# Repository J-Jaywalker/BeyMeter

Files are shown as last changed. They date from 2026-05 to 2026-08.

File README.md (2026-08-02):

# BeyBeetle (WIP)

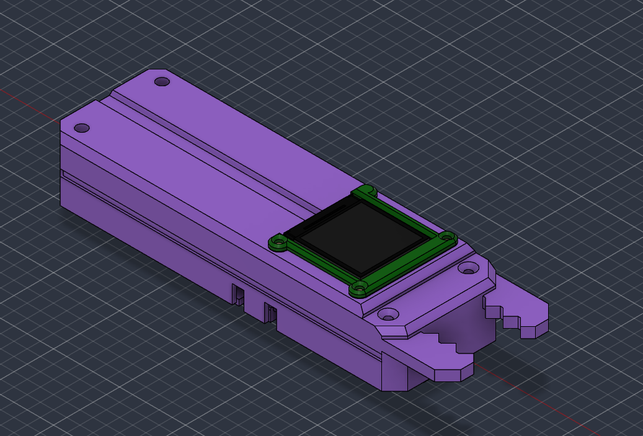
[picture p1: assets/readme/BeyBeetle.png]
The Beybeetle


The BeyBeetle is a custom tool used to measure the angle and RPM of beyblade launches. This repo contains instructions and resources to create a BeyBeetle of your own!

## Design Philosophy

The BeyBeetle is built from easily available, commercial-off-the-shelf (COTS) hardware, so that it can easily be assambled by people who have limited tools, knowledge, resources and space. Even the 3D printed chasis and bill of materials (BOM) are easily aquired through online printing services and hardware vendors. 

All the code and instructions on how to compile, as well as links to recently compiled and up-to-date .uf2 files are included here, so that enthusiasts of all walks are able to build a BeyBeetle should they want to. 

Why a Beetle? I like beetles, they are one of my favourite animals and my other projects feature them as well. 

## What it does

The BeyBeetle reads launch angle from an IMU strapped to your launcher, and will read rotational speed from an IR interrupt sensor once that part is done. On boot it runs a splash while it checks the display, the IMU and the battery gauge, then drops you straight into the bubble screen — there's no menu to fight your way through.

**The bubble screen** is a spirit level for your launcher. Concentric rings mark 15°, 30° and 45° off-axis, and an orange dot moves in real time as you tilt — think of it like a crosshair you're trying to keep centred. Floating beside the dot are your pitch and roll in degrees, each with a little arrow pointing the way you need to correct. Readings are smoothed with an exponential moving average so the display doesn't jitter, and a small battery icon in the corner keeps an eye on charge level so you're not caught out mid-session.

**Locking in** happens through the micro switch the beyblade presses against when it's seated in the launcher. Hold it down and the screen arms itself — the corner crosses spin into place and ARMED tape scrolls down the left edge and along the bottom, so you can tell at a glance that the meter is watching.

**Launching** is just letting go. The instant the beyblade leaves, a green mark drops at exactly the angle you were holding — it flickers for a second, twists from a + into an X, and settles with the angle numbers alongside it. Arm up for your next shot and that mark greys out but stays put, so you can chase the same angle again when the last launch was a good one. Only the previous launch is kept, and it lives behind the live dot so it never gets in the way.

**Sleep** kicks in after three minutes without anything locked in. The screen blanks, the sensors power down and the RP2040 goes fully dormant — no reading, no calculating, nothing. Hold the lock switch for three seconds and it wakes up and boots from scratch, checks and all. Worth knowing: the display's backlight is wired permanently on, so until I run a wire to a spare pin, sleep saves a lot less power than it ought to.

## Roadmap

Launch detection is done — the micro switch catches the moment the beyblade leaves, so the angle that gets recorded is the angle at the point of release rather than whatever you happened to be holding a second beforehand. Everything below builds on that.

**1. RPM mode**
The IR sensor has a home on the board but nothing in the firmware reads it yet. The goal is a reliable launch RPM logged alongside the angle you already get. This is the headline feature and it'll get done properly rather than rushed.

**2. Stats and recall**
Right now the meter remembers your last launch and nothing else, and even that goes when you power it down. Once RPM is in, the records worth keeping — top shoot speed, total launch count — go into flash so they survive a power cycle, with a screen to show them off.

**3. Polish and wrap-up**
The final stretch — finishing the 3D printed chassis, running the backlight wire so sleep actually saves the battery it's meant to, tightening up the UI, and general improvements that come out of actually using the thing in the field.

## First-time setup

Open WSL and run these steps:

**1. Install the toolchain**
```bash
sudo apt install cmake gcc-arm-none-eabi libnewlib-arm-none-eabi build-essential
```

**2. Clone the Pico SDK**
```bash
git clone https://github.com/raspberrypi/pico-sdk ~/pico-sdk
cd ~/pico-sdk && git submodule update --init
echo 'export PICO_SDK_PATH=~/pico-sdk' >> ~/.bashrc && source ~/.bashrc
```

**3. Clone the libraries**
```bash
cd ~/BeyMeter
mkdir lib
git clone https://github.com/libdriver/st7789 lib/st7789
git clone https://github.com/STMicroelectronics/ism330dhcx-pid lib/ism330dhcx-pid
```

That's it — you only need to do this once.

## Every day usage

From `~/BeyMeter`:

```bash
make uf2    # clean build → BeyMeter.uf2
make hex    # clean build → BeyMeter.hex
make build  # incremental build (faster, no clean)
make clean  # wipe build artifacts
```

## Flashing

1. Hold **BOOTSEL** on the Feather and plug it into USB
2. It appears as a drive called `RPI-RP2` in Windows Explorer
3. Drag `BeyMeter.uf2` onto the drive — it reboots automatically

## Previewing the screens

Both stdio outputs are switched off in `CMakeLists.txt`, so there's no serial to watch — turn `pico_enable_stdio_usb` back on if you need it for debugging.

If you just want to see the screens without flashing anything, open [`tools/sim.html`](tools/sim.html) in a browser. It's a reimplementation of the display in JavaScript at the same 240x240, with the mouse aiming the launcher and buttons for the lock switch and the rip cord, so you can watch the arming animation and the launch mark without picking up a beyblade. It doesn't sync itself with the firmware, so if you change how something is drawn in `src/screens.c`, change it there too.

## Hardware

| Component | Connection | Purpose |
|---|---|---|
| Adafruit Feather RP2040 | — | Main board |
| ISM330DHCX IMU | STEMMA QT (I2C) | Tilt and pitch angle measurement |
| MAX17048 LiPo fuel gauge | STEMMA QT (I2C) | Battery management |
| TRCT5000 IR sensor | GPIO | RPM measurement (not read by the firmware yet) |
| D2F micro switch | GPIO |  Beyblde "lock-in" detection |
| Adafruit EyeSPI | SPI | Enables FFC cable connection |
| Adafruit 4313 1.3" 240x240 TFT IPS display | EyeSPI | Display |

Full bill of materials in [`bom/`](bom/).

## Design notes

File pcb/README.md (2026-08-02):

# BeyBeetle carrier board

KiCad 9 project for the board everything plugs into. It's a motherboard rather
than a proper PCBA — every module is an Adafruit breakout sitting in a
through-hole female header, so nothing is soldered down permanently and any part
can be pulled and replaced.

Board as ordered: 80mm x 60mm, 1.6mm FR4, lead-free HASL, 1oz copper, all
through-hole at 2.54mm pitch, ground plane on B.Cu. First run went to JLCPCB on
2026-06-19.

## What's in here

| Path | What it is |
|---|---|
| `BeyBeetle.kicad_pro` | Project file — open this one |
| `BeyBeetle.kicad_sch` | Schematic |
| `BeyBeetle.kicad_pcb` | Board layout |

The `.kicad_prl`, `fp-info-cache` and `BeyBeetle-backups/` are all gitignored —
KiCad regenerates them and they're either huge or specific to whoever's machine
the project was last opened on.

## Getting boards made

No gerbers here — roll your own from the files above so you know they match the
board you're looking at, and so you can tweak it first if you want to. In KiCad:
File → Fabrication Outputs → Gerbers, then Drill Files, then zip the folder and
upload that. Most fabs are happy with KiCad's defaults. Mine came from JLCPCB
with the spec at the top of this page.

## Connectors

Every connection is documented in the schematic, but the short version:

| Ref | Module |
|-----|---|
| J1, J2 | Feather RP2040 (16-pin left, 12-pin right) |
| J3 | MAX17048 fuel gauge |
| J4 | ISM330DHCX IMU (I2C side) |
| J5, J6 | EyeSPI breakout (top and bottom rows) |
| J7 | D2F lock switch |
| J8 | TCRT5000 IR sensor |

One thing to fix on the next revision: EyeSPI `LITE` is a no-connect, so the
display backlight is permanently on and the firmware's sleep mode can't switch
it off. It wants routing to a spare GPIO — 27 (A1) is free.

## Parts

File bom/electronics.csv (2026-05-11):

Reference | Description | Manufacturer | MPN | Qty | Notes
U1 | Feather RP2040 microcontroller | Adafruit | 2795 | 1
U2 | ISM330DHCX 6-DoF IMU | SparkFun / Adafruit | 4502 | 1 | STEMMA QT breakout
U3 | MAX17048 LiPo fuel gauge | Adafruit | 5580 | 1 | STEMMA QT breakout
U4 | TRCT5000 IR reflective sensor | Vishay | TRCT5000 | 1
SW1 | D2F micro switch | Omron | D2F-01 | 1
J1 | Adafruit EyeSPI connector board | Adafruit | 5613 | 1
DSP1 | 1.3" 240x240 TFT IPS display | Adafruit | 4313 | 1

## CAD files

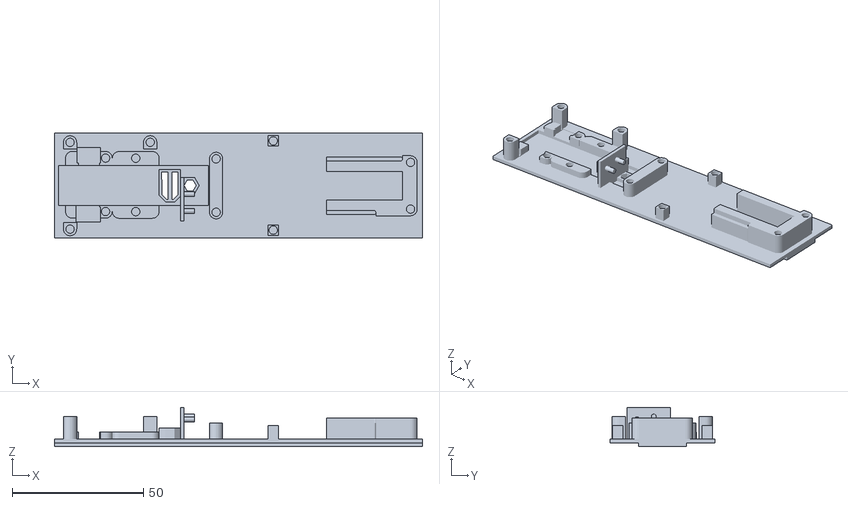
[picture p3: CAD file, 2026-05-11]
bom/enclosure.stl
140.0 x 40.0 x 15.0

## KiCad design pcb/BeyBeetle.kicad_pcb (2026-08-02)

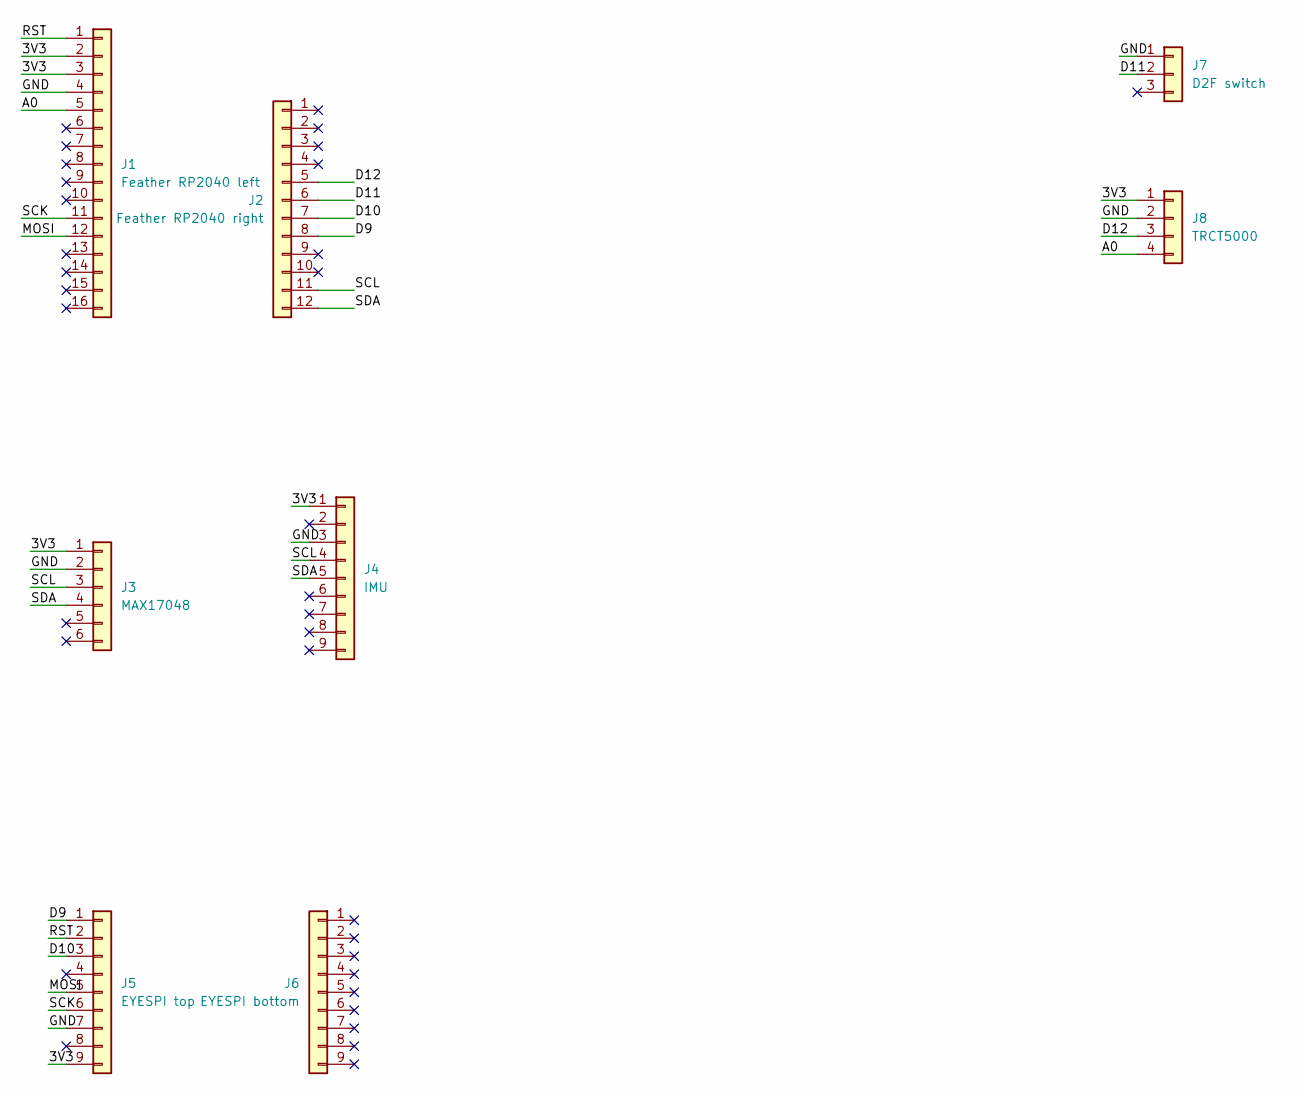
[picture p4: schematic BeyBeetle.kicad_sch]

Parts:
J1: Feather RP2040 left; PinHeader_1x16_P2.54mm_Vertical
J2: Feather RP2040 right; PinHeader_1x12_P2.54mm_Vertical
J3: MAX17048; PinHeader_1x06_P2.54mm_Vertical
J4: IMU; PinHeader_1x09_P2.54mm_Vertical
J5: EYESPI top; PinHeader_1x09_P2.54mm_Vertical
J6: EYESPI bottom; PinHeader_1x09_P2.54mm_Vertical
J7: D2F switch; PinHeader_1x03_P2.54mm_Vertical
J8: TRCT5000; PinHeader_1x04_P2.54mm_Vertical

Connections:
/3V3: J1.2, J1.3, J3.1, J4.1, J5.9, J8.1
/A0: J1.5, J8.4
/D9: J2.8, J5.1
/D10: J2.7, J5.3
/D11: J2.6, J7.2
/D12: J2.5, J8.3
/GND: J1.4, J3.2, J4.3, J5.7, J7.1, J8.2
/MOSI: J1.12, J5.5
/RST: J1.1, J5.2
/SCK: J1.11, J5.6
/SCL: J2.11, J3.3, J4.4
/SDA: J2.12, J3.4, J4.5

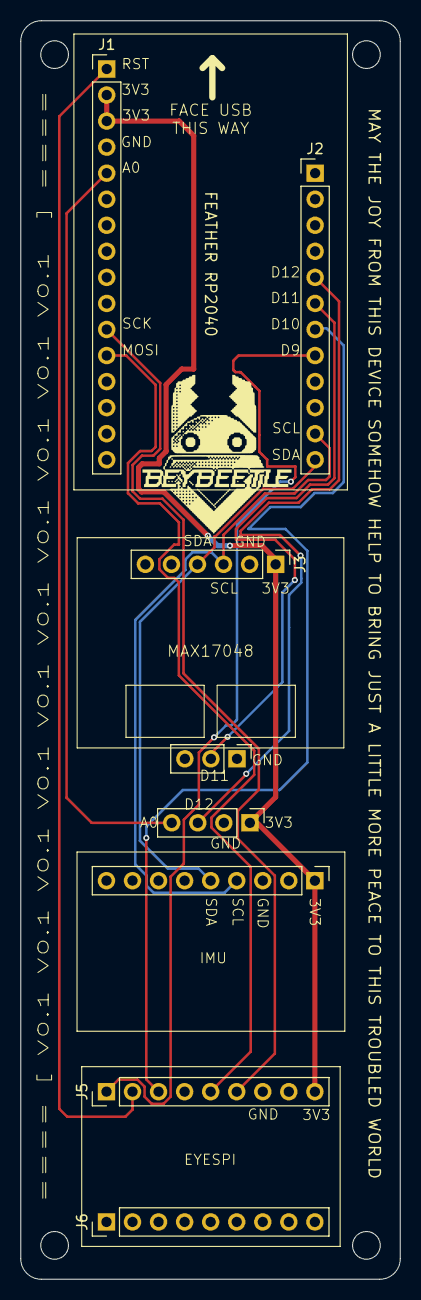
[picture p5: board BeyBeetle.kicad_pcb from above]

Board: 2 copper layers, 37.0 x 122.7 mm, 12 parts (0 on the bottom side), 12 nets.

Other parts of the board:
BL_MOUNT: MountingHole_2.7mm
BR_MOUNT: MountingHole_2.7mm
TL_MOUNT: MountingHole_2.7mm
TR_MOUNT: MountingHole_2.7mm

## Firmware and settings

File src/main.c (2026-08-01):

#include <math.h>
#include "pico/stdlib.h"
#include "hw.h"
#include "screens.h"

// Splash + presence checks. Runs at power-on and again on every wake.
static void boot_sequence(void) {
    screen_splash(1, 3, "Display init");
    sleep_ms(400);

    bool imu_ok = hw_check_imu();
    screen_splash(2, 3, imu_ok ? "IMU ready" : "IMU missing");
    sleep_ms(350);

    bool bat_ok = hw_check_battery();
    screen_splash(3, 3, bat_ok ? "Battery OK" : "No battery");
    sleep_ms(500);
}

// Shuts everything down and parks in DORMANT. Returns only once the lock
// button has been held for WAKE_HOLD_MS — a shorter press goes straight back
// to sleep, so a knock in a bag can't switch the meter on.
static void sleep_until_wake(stmdev_ctx_t *imu) {
    hw_display_sleep();
    hw_backlight(false);
    hw_imu_sleep(imu);
    hw_bat_sleep();

    for (;;) {
        hw_dormant_until_button();

        uint32_t t0 = to_ms_since_boot(get_absolute_time());
        while (!gpio_get(BTN_LOCK)) {                  // still held?
            if (to_ms_since_boot(get_absolute_time()) - t0 >= WAKE_HOLD_MS)
                return;
            sleep_ms(20);
        }
    }
}

int main(void) {
    hw_init();
    boot_sequence();

    // ── IMU setup ────────────────────────────────────────────────────
    stmdev_ctx_t imu = hw_imu_init();

    float roll = 0.0f, pitch = 0.0f;
    float    mark_pitch   = 0.0f, mark_roll = 0.0f;
    uint32_t mark_t0      = 0;
    bool     have_mark    = false;
    uint8_t  bat          = bat_percent();
    uint32_t bat_tick     = 0;
    bool     was_locked   = false;
    uint32_t last_lock    = to_ms_since_boot(get_absolute_time());

    for (;;) {
        uint32_t now = to_ms_since_boot(get_absolute_time());

        int16_t raw[3];
        ism330dhcx_acceleration_raw_get(&imu, raw);

        float ax =  (float)raw[0];
        float ay = -(float)raw[2];
        float az = -(float)raw[1];

        float r_raw = fmaxf(-45.0f, fminf(45.0f,
            atan2f(az, ay) * (180.0f / (float)M_PI)));
        float p_raw = fmaxf(-45.0f, fminf(45.0f,
            atan2f(-ax, ay) * (180.0f / (float)M_PI)));

        roll  = ALPHA * r_raw + (1.0f - ALPHA) * roll;
        pitch = ALPHA * p_raw + (1.0f - ALPHA) * pitch;

        if (++bat_tick >= 40) {
            bat = bat_percent();
            bat_tick = 0;
        }

        bool locked = !gpio_get(BTN_LOCK);
        if (locked) last_lock = now;

        // Lock released = launch: drop a mark where the bubble was sitting.
        // Only the most recent launch is kept.
        if (was_locked && !locked) {
            mark_pitch = pitch;
            mark_roll  = roll;
            mark_t0    = now;
            have_mark  = true;
        }
        was_locked = locked;

        screen_render(roll, pitch, bat, locked,
                      have_mark, mark_pitch, mark_roll, mark_t0);

        // Nothing locked in for SLEEP_IDLE_MS — shut down until woken, then
        // come back up exactly as if the meter had just been switched on
        if (now - last_lock >= SLEEP_IDLE_MS) {
            sleep_until_wake(&imu);

            hw_init();
            boot_sequence();
            imu = hw_imu_init();

            while (!gpio_get(BTN_LOCK))   // don't count the wake hold as a lock
                tight_loop_contents();

            roll = pitch = 0.0f;
            have_mark  = false;
            was_locked = false;
            bat        = bat_percent();
            bat_tick   = 0;
            last_lock  = to_ms_since_boot(get_absolute_time());
        }
    }
}

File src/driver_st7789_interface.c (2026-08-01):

#include "driver_st7789_interface.h"
#include "hw.h"

uint8_t st7789_interface_spi_init(void)    { return 0; }
uint8_t st7789_interface_spi_deinit(void)  { return 0; }

uint8_t st7789_interface_spi_write_cmd(uint8_t *buf, uint16_t len) {
    gpio_put(DISPLAY_CS, 0);
    spi_write_blocking(SPI_PORT, buf, len);
    gpio_put(DISPLAY_CS, 1);
    return 0;
}

void st7789_interface_delay_ms(uint32_t ms) { sleep_ms(ms); }

void st7789_interface_debug_print(const char *const fmt, ...) { (void)fmt; }

uint8_t st7789_interface_cmd_data_gpio_init(void)          { return 0; }
uint8_t st7789_interface_cmd_data_gpio_deinit(void)        { return 0; }
uint8_t st7789_interface_cmd_data_gpio_write(uint8_t value) {
    gpio_put(DISPLAY_DC, value);
    return 0;
}

uint8_t st7789_interface_reset_gpio_init(void)          { return 0; }
uint8_t st7789_interface_reset_gpio_deinit(void)        { return 0; }
uint8_t st7789_interface_reset_gpio_write(uint8_t value) { (void)value; return 0; }

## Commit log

2026-04-26 First pass of IMU functionality
2026-04-26 update makefile and readme for imu
2026-04-26 remove old circuitpython poc
2026-05-11 add bom, new enclosure, update readme and roadmap
    [connectors.csv, electronics.csv, enclosure.stl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]
2026-08-01 fully fix alignment angles
    [main.c]
2026-08-01 rework to use display buffer to hold OLED output, huge rework
    [fb.c, main.c]
2026-08-01 sim stage
2026-08-02 update readme and add pcb assets
    [BeyBeetle.kicad_pcb, BeyBeetle.kicad_sch]
